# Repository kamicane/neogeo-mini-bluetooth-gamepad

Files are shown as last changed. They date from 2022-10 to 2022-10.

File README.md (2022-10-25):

# NeoGeo Mini Bluetooth gamepad

Bluetooth conversion of the NeoGeo mini gamepad using an Esp32.

Uses [ESP32-BLE-Gamepad](https://github.com/lemmingDev/ESP32-BLE-Gamepad) to do Bluetooth things.

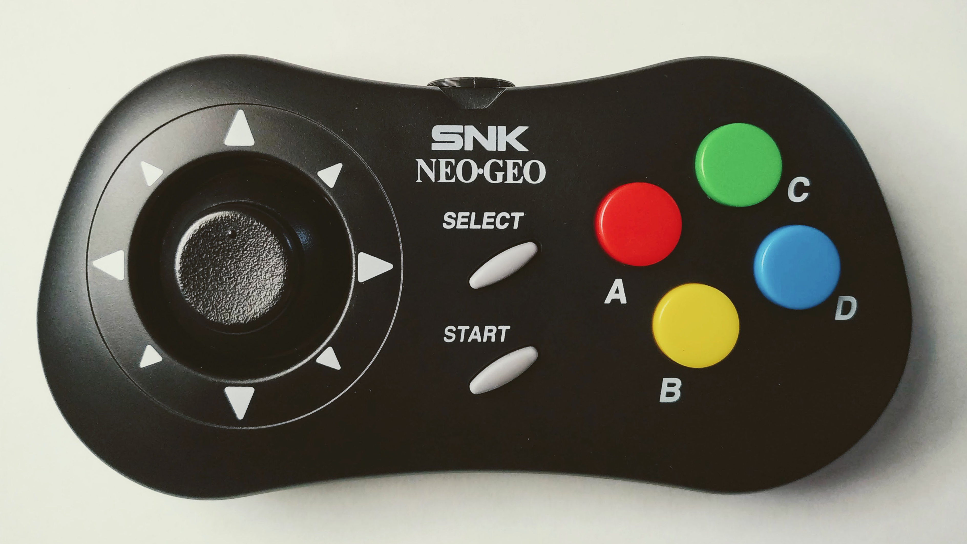
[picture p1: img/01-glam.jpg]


## Features

- Real analog joystick with [scaled radial deadzone](https://github.com/Minimuino/thumbstick-deadzones). Unlike the original controller the output is actually analog
- Optional selectable digital mode with [eight symmetric angular zones](https://gamingprojects.wordpress.com/2017/08/04/converting-analog-joystick-to-digital-joystick-signals/)
- Auto sleep
- Manual sleep
- Analog stick calibration

## Usage

- Wake from sleep: start button
- Force sleep: keep select pressed for 5 seconds
- Auto sleep: no inputs for 5 minutes
- Calibration mode: keep "C" pressed while it wakes from sleep
- Digital mode: keep "D" pressed while it wakes from sleep. This will send the analog stick data as a digital dpad. This setting is preserved in the eeprom
- Analog mode: keep "A" pressed while it wakes from sleep. This will send analog stick data as a left stick. This setting is preserved in the eeprom

## Calibration mode

- Press start to wake the controller from sleep, keeping "C" pressed for a few seconds
- Keep the analog stick in its center position, then press select
- Move the analog stick to its full range, then press select
- The Esp32 saves the calibration data to the internal eeprom then reboots

## Issues

- No external leds: I should add some to see what's going on (connected / disconnected / calibration mode, low battery, etc)
- The only battery that fits properly is only 350mah.

## Parts used

- Platformio: to build and flash the code
- Esp32 board: Lolin32 lite because it's cheap on aliexpress and has an integrated lipo charger
- Lipo battery: I used a 402535 (350mah) because it fits nicely
- USB C connector with breakout board: the shorter & narrower the better
- Stuff to trim the shell: craft files, flush cutters, (low) power tools
- A 3d printer to print the usb gasket
- Superglue to glue the USB connector to the gasket, and the gasket to the shell
- 30awg solid core wire, solder, flux
- Hot air or hot plate to remove the battery connector from the Esp32, and strip the NeoGeo mini pcb of its components
- Double sided tape to secure the Esp32 and the battery

## How I built it

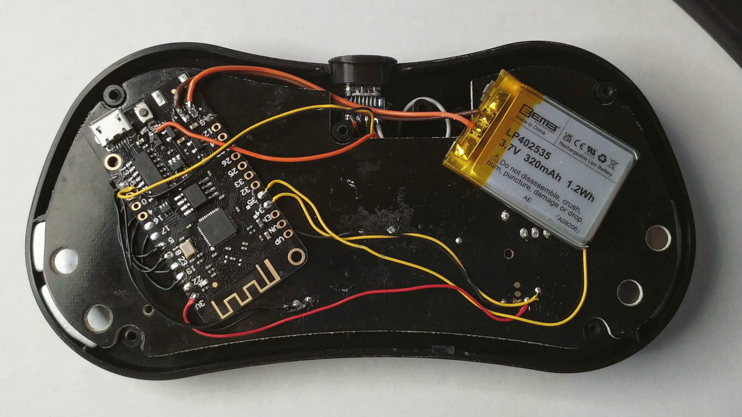
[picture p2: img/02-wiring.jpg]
assembly


- Disassembled the controller, trimmed the shell (look in [/img](/img))
- Desoldered almost all of the components from the NeoGeo pcb to avoid the original encoder getting powered up and consuming battery or interfering with inputs. I kept the 4 pull up resistors that are connected to A B C D and the capacitors that are used to filter the analog stick signals
- Trimmed the analog stick pins flush to make more space for the battery
- Desoldered the battery connector from the Esp32 since it's too tall otherwise
- Soldered all the input pins using the test pads to the Esp32. The A B C D test pads are located under the Esp32. The start button needs to be an RTCIO pin as it will be used to wake the Esp32 from sleep
- Taped the Esp32 to the back of the NeoGeo pcb
- Soldered the external usb connector to the Esp32. I had to use the legs of the CH340C (pin 5 D+, pin 6 D-) and a diode (5v), as the Esp32 does not expose pads for usb connection
- Soldered the battery to the battery pads
- Taped the battery to the back of the NeoGeo pcb

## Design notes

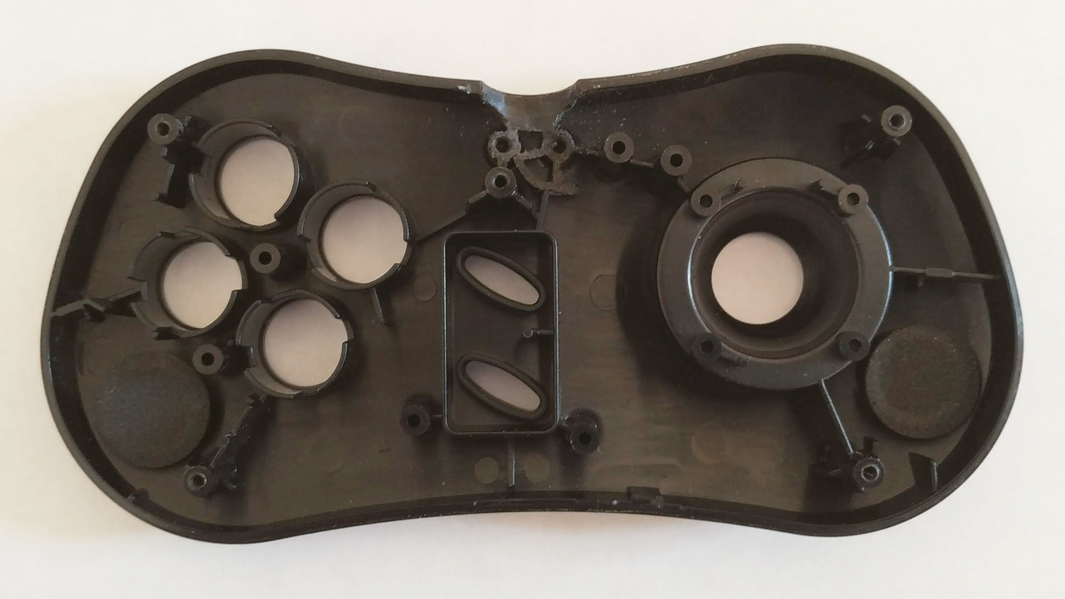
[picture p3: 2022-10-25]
img/04-trim-front.jpg

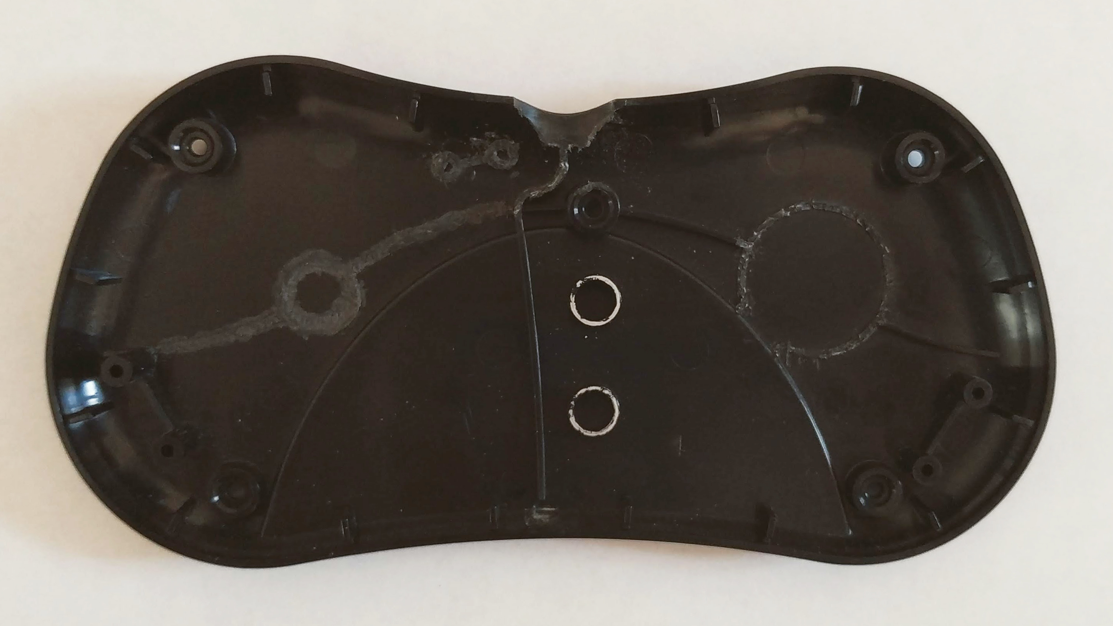
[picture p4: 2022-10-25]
img/03-trim-back.jpg

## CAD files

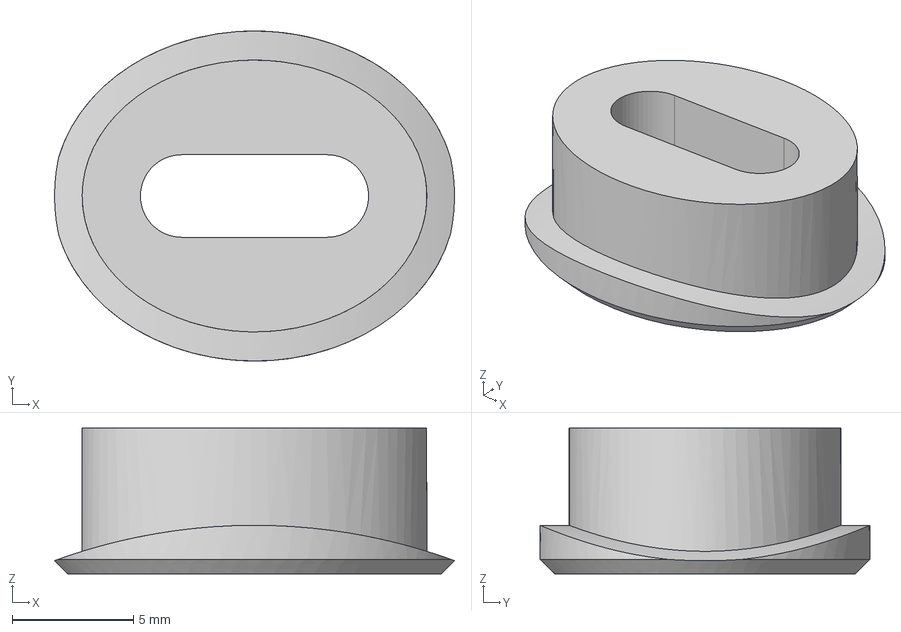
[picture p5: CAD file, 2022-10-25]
3d/NeoGeoMini-USBC.step
16.5 x 13.6 x 6.00 mm

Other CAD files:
3d/NeoGeoMini-USBC.stl

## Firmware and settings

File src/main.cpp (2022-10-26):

#include <Arduino.h>
#include <TickTwo.h>

#include <BluJoy.h>

/* config */

// #define JOY_DEBUG 1

const uint REPORT_RATE = 1000; // micros, 1ms
const uint POLL_RATE = 1000; // micros

const float DEADZONE = 0.20;

const uint SLEEP_TIMEOUT = 5; // minutes
const uint SLEEP_BUTTON_TIMEOUT = 5; // seconds

// pins

const byte AXIS_X_PIN = 34;
const byte AXIS_Y_PIN = 35;

const byte BUTTON_A_PIN = 19; // errnoeously marked "B" in the mini controller
const byte BUTTON_B_PIN = 23; // errnoeously marked "D"
const byte BUTTON_C_PIN = 18; // errnoeously marked "A"
const byte BUTTON_D_PIN = 5;  // errnoeously marked "C"

const byte BUTTON_START_PIN = 15;
const byte BUTTON_SELECT_PIN = 13;

const byte LED_PIN = 22;

/* end config */

BluJoy joy("Neogeo Mini Gamepad", "SNK", DEADZONE);
TaskHandle_t core0_handle;

bool IS_BLE_CONNECTED = false;
bool IS_CLASSIC_CONNECTED = false;

byte LED_STATE = HIGH;

bool CALIBRATION_MODE = false;
bool DIGITAL_MODE = false;

void report ();
void report_calibrate ();
void toggle_led ();
void deep_sleep ();
void ble_conn_check ();
void poll ();

#ifdef JOY_DEBUG
void debug_common ();
TickTwo debug_interval(debug_common, 1000, 0); // 1 second
#endif

TickTwo report_interval(report, REPORT_RATE, 0, MICROS_MICROS);
TickTwo poll_interval(poll, POLL_RATE, 0, MICROS_MICROS);
TickTwo ble_conn_check_interval(ble_conn_check, 1000, 0); // 1 second
TickTwo calibrate_interval(report_calibrate, REPORT_RATE, 0, MICROS_MICROS);
TickTwo nc_led_interval(toggle_led, 1000, 0); // 1 second
TickTwo sleep_timeout(deep_sleep, SLEEP_TIMEOUT * 60000, 0);
TickTwo button_sleep_timeout(deep_sleep, SLEEP_BUTTON_TIMEOUT * 1000, 1);

void stop_all_timers () {
  poll_interval.stop();
  report_interval.stop();
  ble_conn_check_interval.stop();
  calibrate_interval.stop();
  nc_led_interval.stop();
  sleep_timeout.stop();
  button_sleep_timeout.stop();
}

void update_core1_timers () {
  report_interval.update();
  ble_conn_check_interval.update();
  calibrate_interval.update();
  nc_led_interval.update();
  sleep_timeout.update();
  button_sleep_timeout.update();

  #ifdef JOY_DEBUG
  debug_interval.update();
  #endif
}

void update_core0_timers () {
  poll_interval.update();
}

float map_axis_value (uint16_t axis_state_raw) {
  return BluJoy::map_range(axis_state_raw, 0.0, 4095.0, -1.0, 1.0);
}

void read_dpad () {
  joy.set_dpad_analog_state(
    BluJoy::AXIS_LX, BluJoy::AXIS_LY,
    map_axis_value(analogRead(AXIS_X_PIN)), map_axis_value(analogRead(AXIS_Y_PIN))
  );
}

void read_buttons () {
  joy.set_button_state(BluJoy::BUTTON_A, digitalRead(BUTTON_A_PIN));
  joy.set_button_state(BluJoy::BUTTON_B, digitalRead(BUTTON_B_PIN));
  joy.set_button_state(BluJoy::BUTTON_X, digitalRead(BUTTON_C_PIN));
  joy.set_button_state(BluJoy::BUTTON_Y, digitalRead(BUTTON_D_PIN));

  joy.set_button_state(BluJoy::BUTTON_START, digitalRead(BUTTON_START_PIN));
  joy.set_button_state(BluJoy::BUTTON_SELECT, digitalRead(BUTTON_SELECT_PIN));
}

void read_axes () {
  joy.set_axis_state(BluJoy::AXIS_LX, map_axis_value(analogRead(AXIS_X_PIN)));
  joy.set_axis_state(BluJoy::AXIS_LY, map_axis_value(analogRead(AXIS_Y_PIN)));
}

#ifdef JOY_DEBUG
uint32_t report_runs = 0;
uint32_t poll_runs = 0;
#endif

void loop () {
  update_core1_timers();
}

void core0_loop (void *p) {
  for(;;) {
    update_core0_timers();
  }
}

void start () {
  if (digitalRead(BUTTON_C_PIN) == LOW) {
    CALIBRATION_MODE = true;
    #ifdef JOY_DEBUG
    Serial.print("calibration mode\n");
    #endif
  }

  if (CALIBRATION_MODE) {
    #ifdef JOY_DEBUG
    Serial.print("calibration mode\n");
    Serial.print("put all axes in neutral position then press select\n");
    #endif

    calibrate_interval.start();

  } else {

    if (digitalRead(BUTTON_A_PIN) == LOW) {
      DIGITAL_MODE = false;
    } else if (digitalRead(BUTTON_D_PIN) == LOW) {
      DIGITAL_MODE = true;
    } else {
      DIGITAL_MODE = joy.preferences.getBool("digital-mode", false);
    }

    #ifdef JOY_DEBUG
    if (DIGITAL_MODE)
      Serial.print("digital mode\n");
    else
      Serial.print("analog mode\n");
    #endif

    joy.read_calibration_data();

    #ifdef JOY_DEBUG
    for (byte axis = 0; axis < BluJoy::AXIS_COUNT; axis++) {
      Serial.print(String(joy.axis_names[axis]) +
        " min: " + String(joy.get_axis_min(axis)) +
        ", mid: " + String(joy.get_axis_mid(axis)) +
        ", max: " + String(joy.get_axis_max(axis)) + "\n"
      );
    }
    #endif

    joy.connect();

    poll_interval.start();
    report_interval.start();
    ble_conn_check_interval.start();
    nc_led_interval.start();
    sleep_timeout.start();
  }
}

void setup () {
  #ifdef JOY_DEBUG
  Serial.begin(115200);
  Serial.print("setup\n");

  debug_interval.start();
  #endif

  xTaskCreatePinnedToCore(
    core0_loop, /* Function to implement the task */
    "core0_loop", /* Name of the task */
    8192,  /* Stack size in words */
    NULL,  /* Task input parameter */
    0,  /* Priority of the task */
    &core0_handle,  /* Task handle. */
    0 /* Core where the task should run */
  );

  joy.prefs_init();

  pinMode(LED_PIN, OUTPUT);

  pinMode(BUTTON_A_PIN, INPUT);
  pinMode(BUTTON_B_PIN, INPUT);
  pinMode(BUTTON_C_PIN, INPUT);
  pinMode(BUTTON_D_PIN, INPUT);

  pinMode(BUTTON_START_PIN, INPUT_PULLUP);
  pinMode(BUTTON_SELECT_PIN, INPUT_PULLUP);

  pinMode(AXIS_X_PIN, INPUT);
  pinMode(AXIS_Y_PIN, INPUT);

  esp_sleep_enable_ext0_wakeup((gpio_num_t)BUTTON_START_PIN, LOW);

  start();
}

void toggle_led () {
  digitalWrite(LED_PIN, LED_STATE = !LED_STATE);
}

void deep_sleep () {
  stop_all_timers();

  #ifdef JOY_DEBUG
  Serial.print("entering sleep mode\n");
  #endif

  joy.raise_inputs();
  joy.report();

  joy.preferences.putBool("digital-mode", DIGITAL_MODE);

  // delay needed otherwise buttons remain pressed briefly on disconnect (?)
  delay(120);
  esp_deep_sleep_start();
}

float axes_min[2] = { 0.0, 0.0 };
float axes_max[2] = { 0.0, 0.0 };

byte CALIBRATION_STATE = 0;
byte special_btn_state_old = HIGH;

void report_calibrate () {
  read_buttons();
  read_axes();

  byte special_btn_state_new = joy.get_button_state(BluJoy::BUTTON_SELECT);
  bool special_pressed = special_btn_state_old == HIGH && special_btn_state_new == LOW;
  special_btn_state_old = special_btn_state_new;

  if (CALIBRATION_STATE == 1) {
    for (byte axis = 0; axis < 2; axis++) { // first 2 axes, LX and LY
      float state = joy.get_axis_state_raw(axis);
      if (state < axes_min[axis]) {
        axes_min[axis] = state;
        joy.set_axis_min(axis, state);
      } else if (state > axes_max[axis]) {
        axes_max[axis] = state;
        joy.set_axis_max(axis, state);
      }
    }
  } else if (CALIBRATION_STATE == 0) {
    for (byte axis = 0; axis < 2; axis++) { // first 2 axes, LX and LY
      joy.set_axis_mid(axis, joy.get_axis_state_raw(axis));
    }
  }

  if (special_pressed) {
    if (CALIBRATION_STATE == 0) {
      CALIBRATION_STATE = 1;
      #ifdef JOY_DEBUG
      Serial.print("now move all axes full range then press select\n");
      #endif
    } else {
      joy.write_calibration_data();

      #ifdef JOY_DEBUG
      for (byte axis = 0; axis < BluJoy::AXIS_COUNT; axis++) {
        Serial.print(
          String(joy.axis_names[axis]) +
          " min: " + String(joy.get_axis_min(axis)) +
          ", mid: " + String(joy.get_axis_mid(axis)) +
          ", max: " + String(joy.get_axis_max(axis)) + "\n"
        );
      }

      Serial.print("calibration done\n");
      #endif

      calibrate_interval.stop();

      delay(500);
      ESP.restart();
    }
  }
}

void ble_conn_check () {
  if (!joy.is_connected()) { // Bluetooth not connected
    if (IS_BLE_CONNECTED) { // was previously connected (is disconnected)
      #ifdef JOY_DEBUG
      Serial.print("bluetooth disconnected\n");
      #endif
      digitalWrite(LED_PIN, HIGH);
      nc_led_interval.start();
      IS_BLE_CONNECTED = false;
    }
    return;
  } else { // Bluetooth connected
    if (!IS_BLE_CONNECTED) {
      #ifdef JOY_DEBUG
      Serial.print("bluetooth connected\n");
      #endif

      joy.raise_inputs();

      nc_led_interval.stop();
      digitalWrite(LED_PIN, LED_STATE = LOW);

      IS_BLE_CONNECTED = true;
    }
  }
}

void poll () {
  #ifdef JOY_DEBUG
  poll_runs++;
  #endif

  read_buttons();

  if (DIGITAL_MODE) {
    read_dpad();
  } else {
    read_axes();
  }
}

void report () {
  #ifdef JOY_DEBUG
  report_runs++;
  #endif

  // FORCE SLEEP

  if (joy.get_button_state(BluJoy::BUTTON_SELECT) == LOW) {
    if (button_sleep_timeout.state() != RUNNING) button_sleep_timeout.start();
  } else {
    button_sleep_timeout.stop();
  }

  if (joy.is_any_pressed()) {
    sleep_timeout.stop();
    sleep_timeout.start();
  }

  joy.report();
}

#ifdef JOY_DEBUG
void debug_common () {
  for (byte btn = 0; btn < BluJoy::BUTTON_COUNT; btn++) {
    const std::string spacer = (btn < BluJoy::BUTTON_COUNT - 1) ? ", " : "";
    Serial.print(
      String(joy.button_names[btn]) +
      ": " + String(joy.get_button_state(btn)) + spacer.c_str()
    );
  }
  Serial.print(" :: ");
  for (byte axis = 0; axis < BluJoy::AXIS_COUNT; axis++) {
    const std::string spacer = (axis < BluJoy::AXIS_COUNT - 1) ? ", " : "";
    Serial.print(
      String(joy.axis_names[axis]) +
      ": " + String(joy.get_axis_state(axis)) + "(" + String(joy.get_axis_state_raw(axis)) + ")" + spacer.c_str()
    );
  }
  Serial.print(":: DP: " + String(joy.get_dpad_state()) + "\n");
  Serial.print("report runs: " + String(report_runs) + ", poll runs: " + String(poll_runs) + "\n");

  report_runs = 0;
  poll_runs = 0;
}
#endif

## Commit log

2022-10-21 automatic axis calibration, saving preferences
2022-10-21 no need to clear preferences on calibrate
2022-10-21 inverted dpad values whopsie
    [main.cpp]
2022-10-25 add 3d models
    [NeoGeoMini-USBC.step, NeoGeoMini-USBC.stl]
2022-10-26 separate poll timer and configured to run on core0
